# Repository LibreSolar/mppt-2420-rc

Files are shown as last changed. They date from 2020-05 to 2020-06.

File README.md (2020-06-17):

# MPPT charge controller for DIN rail mounting

 First prototype tested, but issues should still be expected.

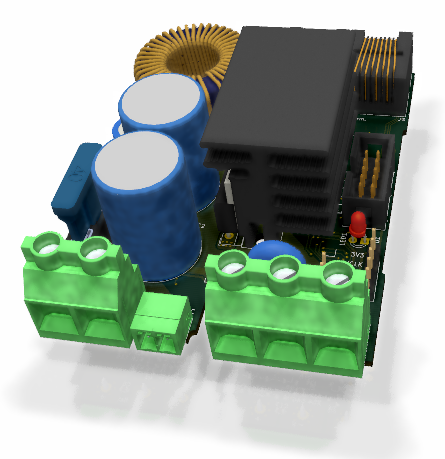
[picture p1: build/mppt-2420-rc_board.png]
MPPT 2420 RC


Schematic: [PDF file](https://github.com/LibreSolar/mppt-2420-rc/raw/master/build/mppt-2420-rc_schematic.pdf)

Bill of Materials: [CSV file](build/mppt-2420-rc_bom.csv) or [interactive HTML BOM](https://libre.solar/mppt-2420-rc/build/mppt-2420-rc_ibom.html)

## Concept description

This charge controller is mainly developed to test the following features:

- Very compact and modular housing design for DIN rail mounting
- Thermal performance and maximum heat dissipation via internal heat sinks
- Performance of the internal OpAmp of the STM32G431 MCU for current measurement
- Dump-load control for small wind turbines using the existing PV reverse blocking MOSFET

## Features

- Solar/Wind input terminal
    - Max. 80V (100V MOSFETs used)
    - DC/DC converter inductor current max. 20A
- Battery output terminal
    - 10 V - 32 V (supporting 12 V and 24 V battery systems)
    - Max. current: 20A (limited by inductor current)
- New STM32G431 ARM MCU with advanced digital power conversion features
- Expandable via Olimex Universal Extension Connector (UEXT)
- Only single LED as power indicator. Additional user interface can be included in separate PCB in front panel housing and connected via UEXT
- CAN interface via RJ45 connectors
- Optional external temperature sensor (10k NTC)
- DIN rail mounting using Phoenix Contact BC series housing

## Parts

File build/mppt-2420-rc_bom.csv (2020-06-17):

Component | References | Value | Footprint | Description | Quantity Per PCB | Manufacturer | PartNumber | Remarks
1 | C44 | 0.22µF | C_Rect_L7.2mm_W3.5mm_P5.00mm_FKS2_FKP2_MKS2_MKP2 | Unpolarized capacitor | 1 |  | 224J63
2 | C7 C9 C10 C11 C20 C22 C29 C30 C31 C32 C36 C48 | 100nF | C_0603_1608 | Unpolarized capacitor | 12 | Murata | GRM188R71H104KA93D
3 | C4 | 100nF | C_0805_2012 | Unpolarized capacitor | 1 | Murata |  | 100V, X7S
4 | C8 C14 C16 C17 C34 | 10nF | C_0603_1608 | Unpolarized capacitor | 5 | Murata | GCM188R72A103KA37D | 100V, X7R
5 | C21 C23 | 10µF | C_0805_2012 | Unpolarized capacitor | 2 | Murata | GRM21BR61E106KA73L | 25V, X5R
6 | C15 | 1nF | C_0603_1608 | Unpolarized capacitor | 1 |  |  | 50V, NP0/C0G
7 | C6 | 1nF | C_0603_1608 | Unpolarized capacitor | 1 | Murata | GRM1885C2A102JA01D | NP0/C0G
8 | C3 C18 C40 | 1µF | C_0805_2012 | Unpolarized capacitor | 3 | Murata | GRJ21BC72A105KE11L | 100V, X7S
9 | C12 C33 C39 C41 C49 | 2.2µF | C_0603_1608 | Unpolarized capacitor | 5 | Murata | GRM188R61E225KA12D | 25V, X5R
10 | C19 | 4.7µF | C_1210_3225 | Unpolarized capacitor | 1 | Murata | GRJ32DC72A475KE11L | 100V, X7S
11 | C1 C2 | 560µF | CP_Radial_D18.0mm_P7.50mm | Polarized capacitor, small symbol | 2 | United Chemi-Con | EKZN101ELL561MM25S | 100V, 2.27A, 18x25
12 | C5 | 820µF | CP_Radial_D10.0mm_P5.00mm | Polarized capacitor, small symbol | 1 | Panasonic | EEU-FR1V821L | 35V, 2.47A
13 | D5 D9 D11 | 12V | D_SOT-23_ANK | Diode zener | 3 | ON Semiconductor | SZBZX84C12LT3G | Alternative: Diodes Inc. BZX84C12-7-F
14 | D10 D16 | 1N4148 | D_SOD-123 | Diode | 2 | Diodes Inc. | 1N4148W-7-F
15 | D8 | 2.5V | D_SOD-123 | Diode zener | 1 | ON Semiconductor | MMSZ5222BT1G
16 | D2 D3 | NRVTS260ESFT1G | D_SOD-123 | Schottky diode | 2 | ON Semiconductor | NRVTS260ESFT1G | Alternative: Nexperia PMEG6020ER,115
17 | D7 D14 D15 | SS14FL | D_SOD-123 | Diode Schottky | 3 | ON Semiconductor | SS14FL | Alternative: Nexperia PMEG4010EGWX
18 | D1 | SS16FP | D_PowerDI-123 | Diode Schottky | 1 | Diodes Inc. | SS16FP | Alternative: DFLS160-7
19 | F1 | 25A | NULL | Fuse (plug-in) | 1 | Littelfuse | 0287025.PXCN
20 | F2 F3 | 600mA | Fuse_1206_3216Metric | Resettable fuse, polymeric positive temperature coefficient, small symbol | 2
21 | HS1 | Heatsink | Fischer_Elektronik_SK573_37,5 | Heatsink | 1 | Fischer Elektronik | SK573-37,5 | 3x MOSFET clips THFU 2 and thermal interface material needed
22 | J3 J4 | 8P8C | RJ45_8P8C | RJ connector, 8P8C (8 positions 8 connected), RJ31/RJ32/RJ33/RJ34/RJ35/RJ41/RJ45/RJ49/RJ61 | 2 | Amphenol FCI | 54602-908LF
23 | J6 | Conn_01x02 | PinHeader_1x02_P2.54mm_Vertical | Generic connector, single row, 01x02, script generated (kicad-library-utils/schlib/autogen/connector/) | 1
24 | J2 | MKDS 5/ 2-9,5 | Phoenix_Contact_MKDS_5-2-9,5 | Generic screw terminal 1x02 | 1 | Phoenix Contact | 1714971
25 | J1 | MKDS 5/ 3-9,5 | Phoenix_Contact_MKDS_5-3-9,5 | Generic screw terminal 1x03 | 1 | Phoenix Contact | 1714984
26 | J5 | Phoenix Contact MC 1,5 | Phoenix_Contact_MC_1,5_2-G-3,81 | Generic connector, single row, 01x02, script generated (kicad-library-utils/schlib/autogen/connector/) | 1 |  |  | Ext. Temperature Sensor
27 | J7 | UEXT | Box_Header_2x05x2.54mm_Straight | Olimex UEXT connector (2x5 box header) | 1
28 | JP1 | Jumper_NC_Small | PinHeader_1x02_P2.54mm_Vertical | Jumper, normally closed, small symbol | 1
29 | L1 | 33µH | L-FERYSTER-DTMSS-27 | Inductor with iron core | 1 | Feryster | DTMSS-27/0,033/20-H
30 | L2 | 4.7µH | L_0805_2012Metric | Inductor, small symbol | 1 | Murata | LQM21PN4R7NGRD
31 | L3 | 47µH | Bourns_SRN6045TA | Inductor, small symbol | 1 | Tayo Yuden | NR6045T470M | Alternative: Bourns SRR6045TA-470Y
32 | LED1 | red | LED_D3.0mm | Light emitting diode | 1 | Lite-On | LTST-C190KRKT | red
33 | Q9 | DMP10H4D2S | SOT-23 | P-MOSFET transistor, gate/source/drain | 1 | Diodes Inc. | DMP10H4D2S-7
34 | Q1 Q2 Q8 | IPP045N10N3G | TO-220-3_Vertical | N-MOSFET transistor, gate/drain/source | 3 | Infineon | IPP045N10N3G
35 | R12 | 0R | R_0603_1608 | Resistor | 1 | Yageo | RC0603FR-070RL
36 | R40 | 100R | R_0603_1608 | Resistor | 1 | Yageo | RC0603FR-07100RL
37 | R13 R17 | 100k | R_0603_1608 | Resistor | 2 | Yageo | RC0603FR-07100KL
38 | R7 R24 R39 R41 R45 R64 R65 R66 | 10k | R_0603_1608 | Resistor | 8 | Yageo | RC0603FR-0710KL
39 | R22 | 120R | R_1206_3216 | Resistor | 1
40 | R56 | 1M | R_0603_1608 | Resistor | 1 | Yageo | RC0603FR-071ML
41 | R15 R42 | 1k | R_0603_1608 | Resistor | 2 | Yageo | RC0603FR-071KL
42 | R8 R10 R14 R20 R21 | 2.2k | R_0603_1608 | Resistor | 5 | Yageo | RC0603FR-072K2L
43 | R4 | 2R2 | R_1206_3216 | Resistor | 1 | Yageo | RC1206FR-072R2L
44 | R6 | 2m | R_Bourns_CRE2512 | Resistor | 1 | Bourns | CRE2512-FZ-R002E-3
45 | R23 R60 | 33k | R_0603_1608 | Resistor | 2 | Yageo | RC0603FR-0733KL
46 | R1 R2 R3 R5 | 3R3 | R_0805_2012 | Resistor | 4 | Yageo | RC0805FR-073R3L
47 | R18 | 5.6k | R_0603_1608 | Resistor | 1 | Yageo | RC0603FR-075K6L
48 | R9 R11 | 68k | R_0603_1608 | Resistor | 2 | Yageo | RC0603FR-0768KL
49 | RT1 | 10k | R_0603_1608 | Temperature dependent resistor, negative temperature coefficient | 1 | TDK | NTCG163JF103FT1S
50 | RV2 | 82V | RV_Disc_D12mm_W4.3mm_P7.5mm | Voltage dependent resistor | 1 | Bourns | MOV-10D820K
51 | SWD1 | ST_Nucleo_SWD | PinHeader_1x05_P2.54mm_Vertical | STM32 Nucleo Board SWD connector (5 pins w/o SWO) | 1 | Any | Standard 2.54 mm pitch 1x5 pin header
52 | T2 T6 T10 | MMBT3904 | SOT-23 | 0.8A Ic, 45V Vce, NPN Transistor, SOT-23 | 3 | Diodes Inc. | MMBT3904-7-F
53 | U6 | 24AA32 | SOT-23-5 | Microchip 24AAxx/24LCxx I2C EEPROM, SOT-23-5 | 1 | Microchip | 24AA32AFT-I/OT
54 | U1 | LM5107 | SOIC-8_3.9x4.9mm_Pitch1.27mm | 100V / 1.4-A Peak Half Bridge Gate Driver | 1 | Texas Instruments | LM5107MAX/NOPB
55 | U4 | LMR16006X | SOT-23-6 | SIMPLE SWITCHER® 4V to 60V, 600mA Step-Down Regulator with Low Iq | 1 | Texas Instruments | LMR16006XDDCR
56 | U2 | STM32G431CBTx | LQFP-48_7x7mm_P0.5mm | ARM Cortex-M4 MCU, 128KB flash, 22KB RAM, 170MHz, 1.71-3.6V, 66 GPIO, LQFP-48 | 1 | ST Microelectronics | STM32G431CBT6
57 | U5 | TCAN334 | SOIC-8_3.9x4.9mm_Pitch1.27mm | High-Speed CAN Transceiver, 1Mbps, 3.3V supply, low power standby mode, shutdown mode, SOT-23-8/SOIC-8 | 1 | Texas Instruments | TCAN334DR
58 | U3 | TLV9001 | SOT-23-5 | SOT-23-5 | 1 | Texas Instruments | TLV9001IDBVR | Alternative: TLV6001, MCP6001
59 | XF1 | ATO blade fuse | Keystone-Fuse-3557-2 | Fuse holder | 1 | Keystone | 3557-2
60 | Y1 | 8MHz | Resonator_Murata_CSTNE | Two pin crystal | 1 | Murata | CSTNE8M00GH5C000R0 | 0.07%

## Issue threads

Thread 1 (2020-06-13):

Capacitor rev. 0.1

BernhardEllmann, 2020-06-13:
Dear Martin,

both circuit diagrams rev. 0.1 and rev. 0.1.1 specify C1 + C2 as 560 uF
BOM for rev. 0.1.1 lists 560 uF/100V
you commented that the footprint of C1 + C2 should be reduced when building the circuit on board version 0.1

do you recommend:
- to reduce 560 uF --> ?
- or to reduce 100V --> ?
- or to reduce both 560 uF / 100V --> ? / ?

my use-case is:
- solar panel 21,4 V OC, 17,5 V MP
- battery 36 V

can you please confirm that the controller can handle this? The circuit diagram does not mention that the circuit can actually be used in 2 directions

martinjaeger, 2020-06-14:
Yes, boost operation is possible, as it is a synchronous buck converter.

For the nominal 36V battery (i.e. 42V max.) also 63V or 80V caps should work fine. Slightly lower capacity (like 390uF) is also OK. Most important is that the caps allow high ripple current. If you take one from the same series as specified in the BOM everything should be fine.

BernhardEllmann, 2020-06-14:
fine, thanks a lot!

Closed 2020-06-14.

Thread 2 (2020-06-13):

faulty link?

BernhardEllmann, 2020-06-13:
right-click on
mppt-2420-rc_bom_v0.1.1.csv
at
https://github.com/LibreSolar/mppt-2420-rc/tree/master/bom

and click on
"Ziel speichern unter .. "
yields some wrong file,

whereas using "clone or Download" / "download ZIP" works well.

martinjaeger, 2020-06-14:
You should left-click on the link and then download the raw file. That's the way how github displays content of text files.

Closed 2020-06-14.

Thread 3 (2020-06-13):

BOM: some faulty part numbers

BernhardEllmann, 2020-06-13:
some part numbers in BOM, .csv-version, appear to be faulty:

- line 8 (C15): part GRM188R71H104KA93D has wrong value (0,1 uF instead of 1nF
- line 39 (R12): part RC0603FR-0710KL has wrong value (10K instead of 0R)
- line 43 (R64, R65, R66): part RC0805FR-0710KL has wrong footprint (or wrong data specified in column F)
- line 47 (R8, R10, R14): part RC0603FR-0710KL has wrong value (10k instead of 2k2)
- line 52 (R60): part RC0805FR-0733KL has wrong footprint (or wrong data specified in column F)
- line 55 (R9, R11): part RC0603FR-0710KL has wrong value (10K instead of 68K)

martinjaeger, 2020-06-14:
Thanks for finding these errors. I didn't realize them as I have all those standard parts available anyway and don't order them with each PCB.

- Line 8: Ok, taking out the specific part number, as the manufacturer doesn't matter for this part.
- Line 39: Ok, corrected.
- Line 43: Part numbers were wrong, 0603 is correct.
- Line 47: Ok, corrected.
- Line 52: 0603 footprint is correct, part number was wrong.
- Line 55: Ok, corrected.

Will push the corrections with next update.

BernhardEllmann, 2020-06-14:
Line 8: so the same type can be used as for C6, eventually? (Same footprint, same value)
If yes, the two lines 8 & 9 could be merged

btw:
C15 got changed from v0.1 to v0.1.1 (from 100 nf to 1 nF)
I guess for biuiding the circuit on board version 0.1, I shall use the updated value?

martinjaeger, 2020-06-14:
Yes, correct, 1nF can be used and the same caps can be used for both.

The snubber capacitor C6 has some influence on voltage ringing and EMC behavior and still has to be fine-tuned in the final design, so I did not merge both of them yet. But at the moment we can use the same caps for both (even though C15 doesn't need that high voltage rating).

Closed 2020-06-26.

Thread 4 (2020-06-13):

Schottky Diode SS14FL discontinued

BernhardEllmann, 2020-06-13:
Schottky Diode SS14FL dircontinued acc. to Mouser homepage (2020-06-13)

--> what should be used as a replacement?

martinjaeger, 2020-06-14:
An Alternative is already mentioned in the "Alternative" column of the BOM: Nexperia PMEG4010EGWX

Or you use the same 60V / 2A variant as suggested for the CAN bus port (see other issue).

BernhardEllmann, 2020-06-14:
oh, yes, sorry.
I had to modify my excel for several reasons, and I happened to delete this information

Closed 2020-06-14.

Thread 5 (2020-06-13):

BOM incomplete (MOSFET clips)

BernhardEllmann, 2020-06-13:
BOM appears to be incomplete:
MOSFET clips for heatsink are not included.

martinjaeger, 2020-06-14:
Thanks for these remarks. Those mechanical parts were currently not part of the BOM as KiCad does not have any feature to add parts that are not placed on the board... I will think about a way how to do that without adding them manually to the BOM after export.

The correct Heatsink clip is THFU 2. I will at least add it as a remark. Insulating pads are specified in detail yet, I just took one that I still had. For the fuse you can use Littelfuse 0287025.PXCN.

BernhardEllmann, 2020-06-14:
Why do you recommend THFU 2?
THFU 1
- is suitable for TO 220
- is suitable for SK 573
- has same strenght (60 N)
- is a tiny bit less bulky, according to technical drawing on Fischer Website (10,3 mm instead of 10,5 mm)

Have you tried THFU 1?

martinjaeger, 2020-06-14:
Good question. That one was recommended to me by Fischer Elektronik when I talked to them at Embedded World this year, so I didn't check any other option.

The THFU 2 was quite hard to mount, you needed lots of force to clip it in. Maybe THFU 1 is a bit easier to mount... but didn't try.

BernhardEllmann, 2020-06-14:
ok, I will order both and let you know :)

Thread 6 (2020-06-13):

replacement for heatsink Fischer SK 573 37,5

BernhardEllmann, 2020-06-13:
Heatsink Fischer Elektronik SK 573 37,5 seems to be hard to get.
is there any alternatives from other manufacturers?

martinjaeger, 2020-06-14:
Ok, that seems true. Only Arrow seem to have it in stock: https://octopart.com/search?q=Fischer+Elektronik+SK+573+37%2C5&currency=EUR&specs=0

I got a sample directly from Fischer Elektronik.

If you don't populate the UEXT connector J7, quite a lot of other heat sinks should be useable if the MOSFETs are screw-mounted to the heat sink. This particular one fits very well into the available space and doesn't require threads in the heat sink as it uses clips. I didn't do any research if other heat sinks fit as nicely as this one. As stated in the Readme, I still have to validate if the heat dissipation inside the housing is enough for the 20A in general.

BernhardEllmann, 2020-06-14:
the longer 50mm version is available at Farnell.
using that one after trimming would be a workaround

martinjaeger, 2020-06-14:
Ah, yes, black is recommended.

BernhardEllmann, 2020-06-14:
"If you don't populate the UEXT connector J7 ..." (cited from above)
What is the minimum setup required for programming the MC when using the v0.1 board
SWD and USART port?
(There is no debug serial port available on v0.1)

martinjaeger, 2020-06-14:
Only the SWD is needed for programming. But an USART is useful for debugging. For the v0.1 board I am using the USART in the UEXT connector, but as there was another USART left, I added a second one to the v0.1.1 board.

BernhardEllmann, 2020-06-14:
This means that you recommend to populate the UEXT port, did I understand that right?

I'm asking, because on the schematic (PDF, Page 4) the keyword "USART" shows up in combination with the keyword SWD: "STM Nucleo SWD and USART" (blue text)
(sorry. since I'm not too familiar with these ports yet, it's a little bit confusing for me)

martinjaeger, 2020-06-14:
The UEXT port is very useful, as you can add lots of extensions to the board, see here: https://www.olimex.com/Products/Modules/

However, if you need the space for a different heat sink and still want to use the USART for debugging (which I highly recommend), you can also solder those two wires to the correct pins at the UEXT connector only.

The text refers to SWD and USART at the same time as both are quite useful during development and most programmers / debug probes (including the ST-Link v2 as included in many ST nucleo boards) also have the USART pins that you can use for printing serial debug information.

BernhardEllmann, 2020-06-14:
sounds good, thank you!

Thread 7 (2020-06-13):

BOM consolidation: C8, C14, C16, C34 vs. C17

BernhardEllmann, 2020-06-13:
Why use different types for:
- C8, C14, C16: 50V
- C17: 100V

could 100V type be used for all 4 components?

martinjaeger, 2020-06-14:
Thanks for these enhancements.

- C17 etc. (10 nF): I agree this makes sense. Will update this.
- C41 etc. (2.2uF): I forgot to add the part number in the schematic for one of them, so the BOM export puts it in a separate line as their information was not *exactly* the same. Just added the number also for C41, so it will get to the same line for next export.
- D2, D3: Oops, forgot to specify as I just took one of the SS14FL. We could actually consolidate the different types of Schottky diodes better and just use 60V / 2A versions everywhere. Suitable parts:
Nexperia PMEG6020ER,115 or ON Semi NRVTS260ESFT1G
- J3, J4: Amphenol FCI 54602-908LF (will add it to the BOM aswell)

BernhardEllmann, 2020-06-14:
thanks to your here too !

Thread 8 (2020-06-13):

replacement for F2, F3?

BernhardEllmann, 2020-06-13:
In case Fuse 600mA 1206 is not available:
- use slightly lower value instead (e.g. 460mA)?
- use slightly higher value instead (e.g. 750mA)?
please give a range.

martinjaeger, 2020-06-14:
I assume you don't need the CAN bus part for your application anyway, so you can leave out that sheet of the circuit completely.

The fuse protects the RJ45 wires from overcurrent and they can handle around 300 mA per wire pair (we use two pairs). Allowing less current is always safe.

BernhardEllmann, 2020-06-14:
ok, good to know, thank you!

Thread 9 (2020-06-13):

J5 external temperature sensor

BernhardEllmann, 2020-06-13:
what happens if J5 remains open?

If I want to use J5:
- what sensor do i need to use?
- what connector matches with J5?
Please specify

martinjaeger, 2020-06-14:
The firmware assumes 25°C if no external sensor is connected. And as Li-Ion charging voltages are not temperature-dependent, it's only relevant for lead-acid batteries.

You can use any wired 10k NTC with a connector from Phoenix Contact FMC 1,5 3,81 series (or similar one from other brands). A suitable Phoenix Contact part number is 1745894.

Thanks for the remark, I will add this to the schematic.

BernhardEllmann, 2020-06-14:
ok, fine, thanks a lot!

Closed 2020-06-14.

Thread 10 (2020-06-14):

HV / LV side to 3.3V

BernhardEllmann, 2020-06-14:
The diagram on Page 3 page of PDF "mppt-2420-rc" (sheet "/Power Supply/") defines "HV +" as power input, which is linked to DCDC_HV+ on Page 1 (sheet "/").
Accordingly, the circuit board (version v0.1) is hardwired to DCDC_HV+

At the same time, Page 3 states: "Use voltage from low side if available."
This seems to offer a choice which is actually not available.

Please explain.

martinjaeger, 2020-06-14:
The Power Supply sheet uses the name HV+ internally, but it's connected to the DCDC_HV+ net on the top level schematic.

The circuit around Q9 in the Power Supply sheet "chooses" automatically, which rail (HV+ or LV+) it uses for internal power supply. If LV+ is available (>around 12V), it is used instead of HV+ to increase efficiency.

BernhardEllmann, 2020-06-14:
well, that's a nice feature :)

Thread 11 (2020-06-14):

boost mode operation?

BernhardEllmann, 2020-06-14:
I'm still wondering, if / why the controller can operate in boost mode (solar panel @18 V; Battery @ 36)

If I understood you correctly on the phone, this would involve connecting the battery to the HV side, and the solar panel to the LV side. But then the current would have opposite direction, right?
- Can the MOSFETS cope with that?
- What about "MOSFET for reverse polarity protection and PV reverse current blocking" (Schematic, Page 2, sheet "DC/DC", blue text next to Q8)

Is there any tutorial available?

martinjaeger, 2020-06-14:
Yep, see here: https://learn.libre.solar/development/dcdc_converter.html

The reverse polarity protection MOSFET will be switched on as soon as the DC/DC power stage is switched on. And if you use a connector where you can't connect the converter in reverse polarity, you can even use the terminal that goes directly to GNDPWR (marked W- for wind negative terminal).

BernhardEllmann, 2020-06-14:
nice.
But it does mean that the MOSFETs have to be able to cope with bidirectional current, right?
What about the in-built diodes in the MOSFETs, as indicated in the wiring symbols?

martinjaeger, 2020-06-14:
A MOSFET that is switched on does not care about the direction of current flow. And when it's off, current can only go in one direction (through the [body diode](https://en.wikipedia.org/wiki/Power_MOSFET#Body_diode)). And that's the same direction as you would have in a non-synchronous buck or boost converter.

BernhardEllmann, 2020-06-14:
ok, I think I got it now, thank you!

Closed 2020-06-25.

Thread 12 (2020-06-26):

Interference of external and internal OpAmp

martinjaeger, 2020-06-26:
The board has an external OpAmp as stuffing option. However, during testing with the external OpAmp, we realized that the microcontroller pins influence the OpAmp operation even if they are in high impedance state.

Solution: Cut the the three traces to the internal OpAmp (see following picture) with a knife if the external one should be used.

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

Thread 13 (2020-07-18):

SMPS power supply HV+/LV+ switching not working properly

martinjaeger, 2020-07-18:
For 24V systems, the maximum voltage ratings of T2 base are exceeded, which leads to excessive current draw.

Preliminary solutions:
- Replace T2 with NMOS (e.g. BSS138)
- Remove T2 completely (and use only low voltage side for power supply)

Permanent fix yet to be developed.

For details see [Forum post](https://talk.libre.solar/t/building-mppt-2420-rc-solar-charger/194/2).

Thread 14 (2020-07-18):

Q8 gate drive via half bridge driver via not sufficient

martinjaeger, 2020-07-18:
Already in previous MPPT designs, the reverse blocking MOSFET (here: Q8) was supplied via the low-side gate driver of the half bridge, switching it on automatically when the power stage is on.

In this design the reverse blocking MOSFET can be used also as a dump load switch for wind turbine applications (with the generator negative connected via separate terminal W-), so it should be possible to switch it on even if the power stage is off. R12 allows to supply power directly from the 12V rail.

Unfortunately, the 10k pull-up resistor R45 necessary for this use case prevents the MOSFET Q8 to stay on if powered by the low-side driver, especially at low duty cycles.

Preliminary solution:
- Populate 0R resistor R12 (leading to slightly higher power consumption when power stage is off)
- Replace R45 with a 0R resistor (solder bridge) and remove R12 and T6

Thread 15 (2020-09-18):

mppt-2420 - support for higher voltage and current

lwqcz, 2020-09-18:
Hi there,

what I need to change to support 300V input from my photovoltaic panels and 40A current to battery?

Just different inductor and MOSFETs?

Thank you.

martinjaeger, 2020-09-18:
That would be a completely different design, probably with a two-phase power stage.

lwqcz, 2020-09-29:
I see... And what about an idea of an addon module for higher voltage and load, isolated via optocoupler?

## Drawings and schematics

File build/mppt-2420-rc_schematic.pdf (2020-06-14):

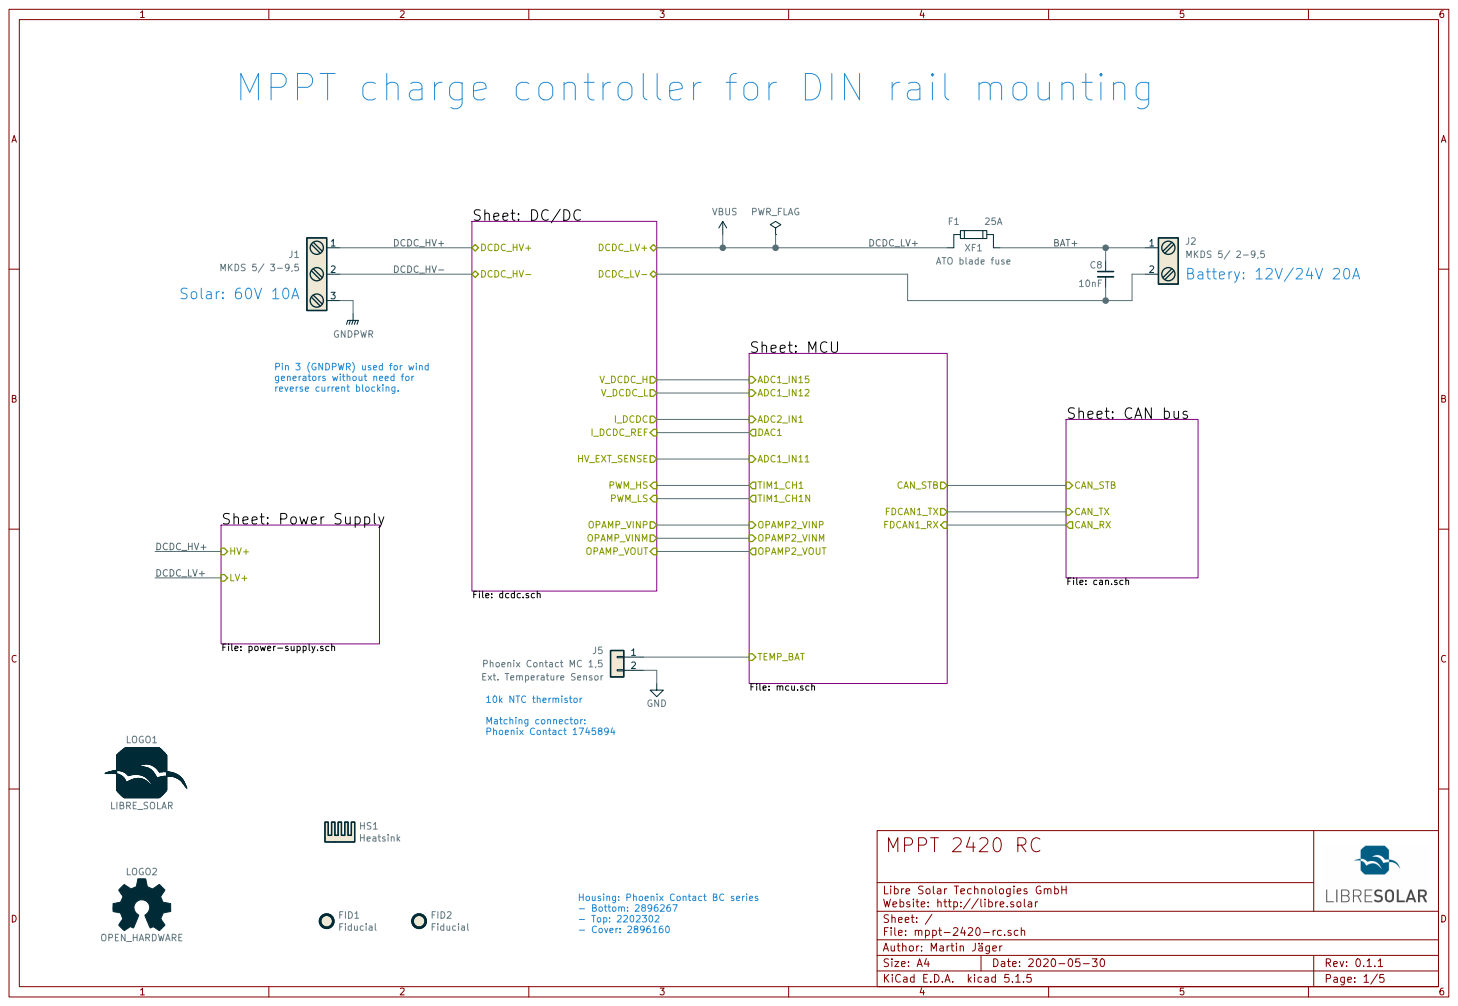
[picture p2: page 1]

10k NTC thermistor Matching connector: Phoenix Contact 1745894 MPPT charge controller for DIN rail mounting

File: can.sch CAN_TX CAN_RX CAN_STB Sheet: DC/DC

XF1 ATO blade fuse GNDPWR

Pin 3 (GNDPWR) used for wind
generators without need for
reverse current blocking.

File: power-supply.sch

J5 Phoenix Contact MC 1,5 Ext. Temperature Sensor

File: mppt-2420-rc.sch Sheet: / Libre Solar Technologies GmbH
Website: http://libre.solar

Housing: Phoenix Contact BC series
- Bottom: 2896267
- Top: 2202302
- Cover: 2896160

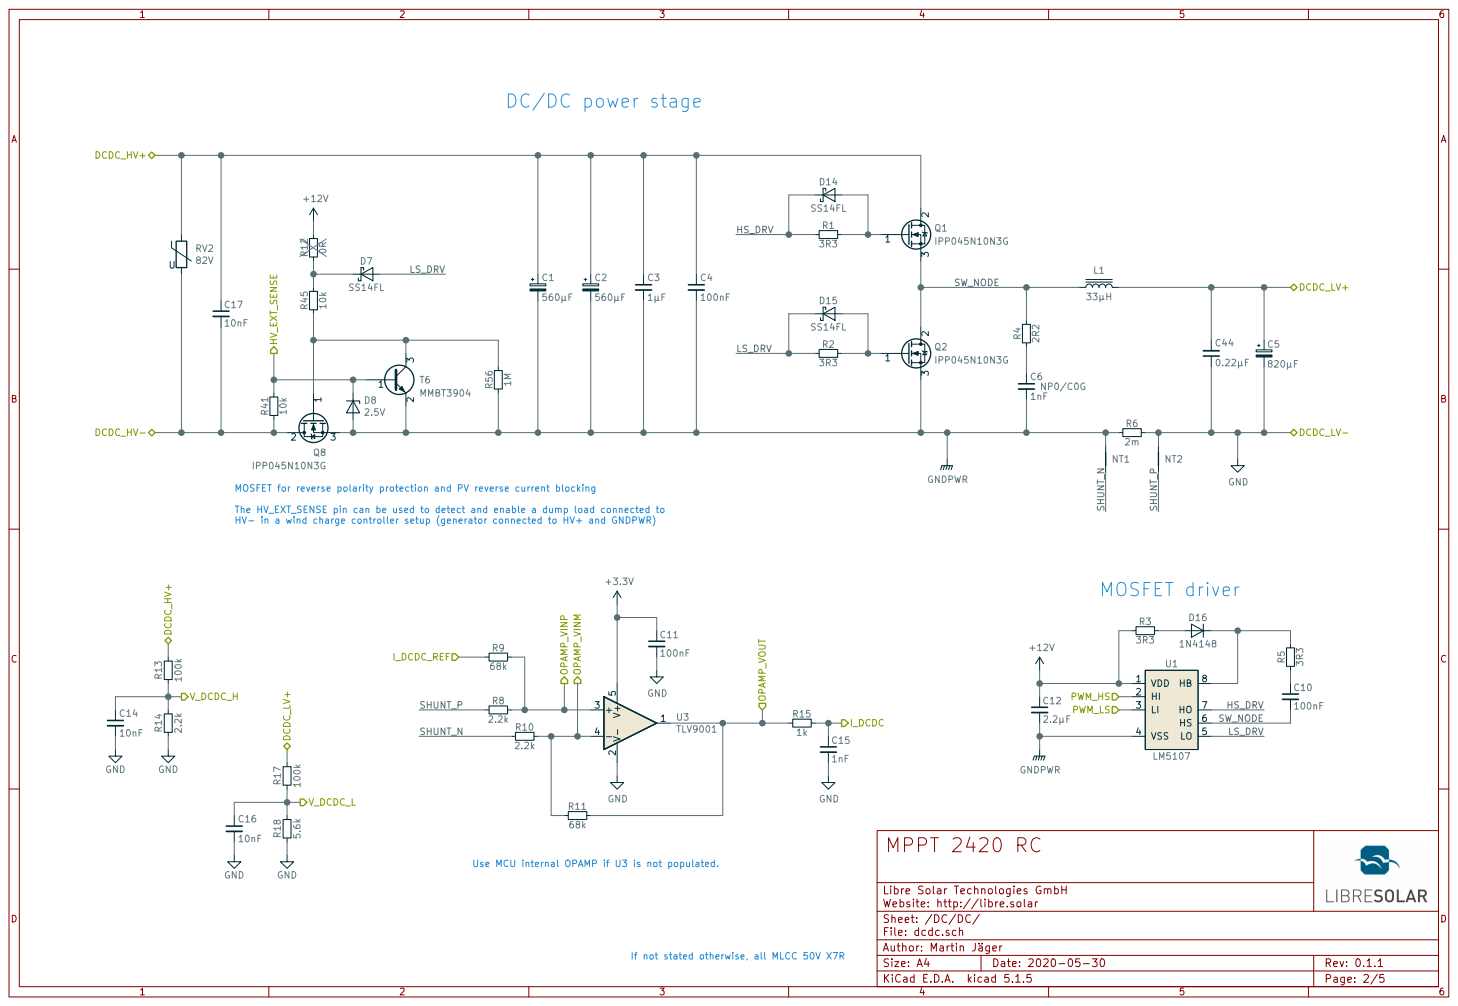
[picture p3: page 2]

DC/DC power stage

HS_DRV MOSFET for reverse polarity protection and PV reverse current blocking

The HV_EXT_SENSE pin can be used to detect and enable a dump load connected to
HV- in a wind charge controller setup (generator connected to HV+ and GNDPWR)

Use MCU internal OPAMP if U3 is not populated.

File: dcdc.sch Sheet: /DC/DC/ Libre Solar Technologies GmbH

If not stated otherwise, all MLCC 50V X7R

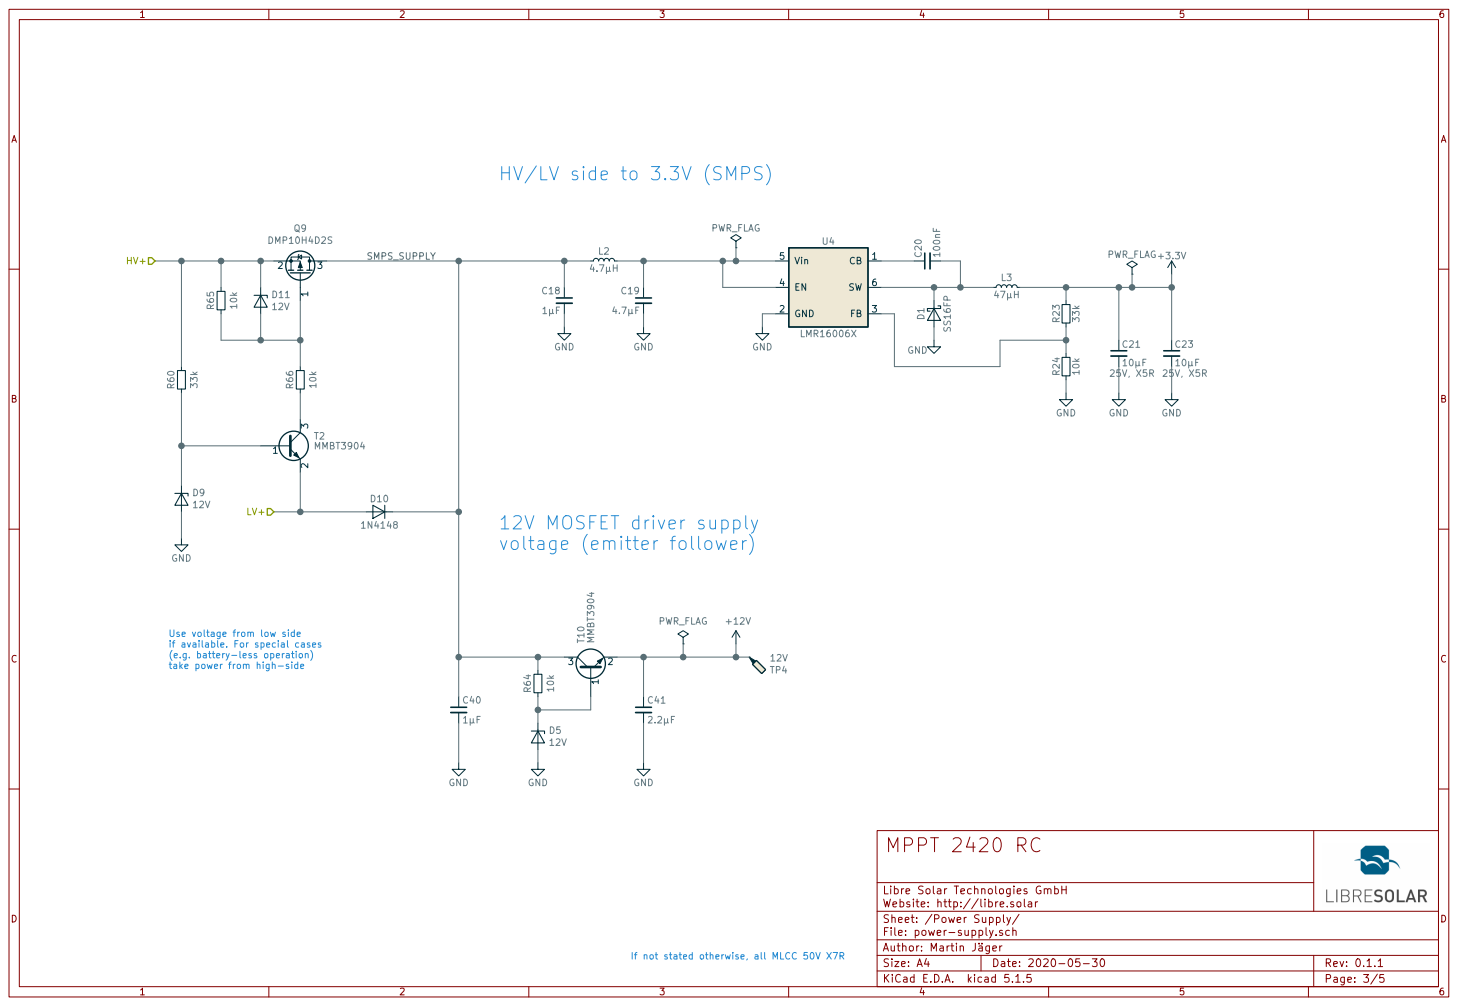
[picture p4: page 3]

HV/LV side to 3.3V (SMPS)

Use voltage from low side
if available. For special cases
(e.g. battery-less operation)
take power from high-side

Website: http://libre.solar GND

Libre Solar Technologies GmbH

Sheet: /Power Supply/
File: power-supply.sch
Author: Martin Jäger

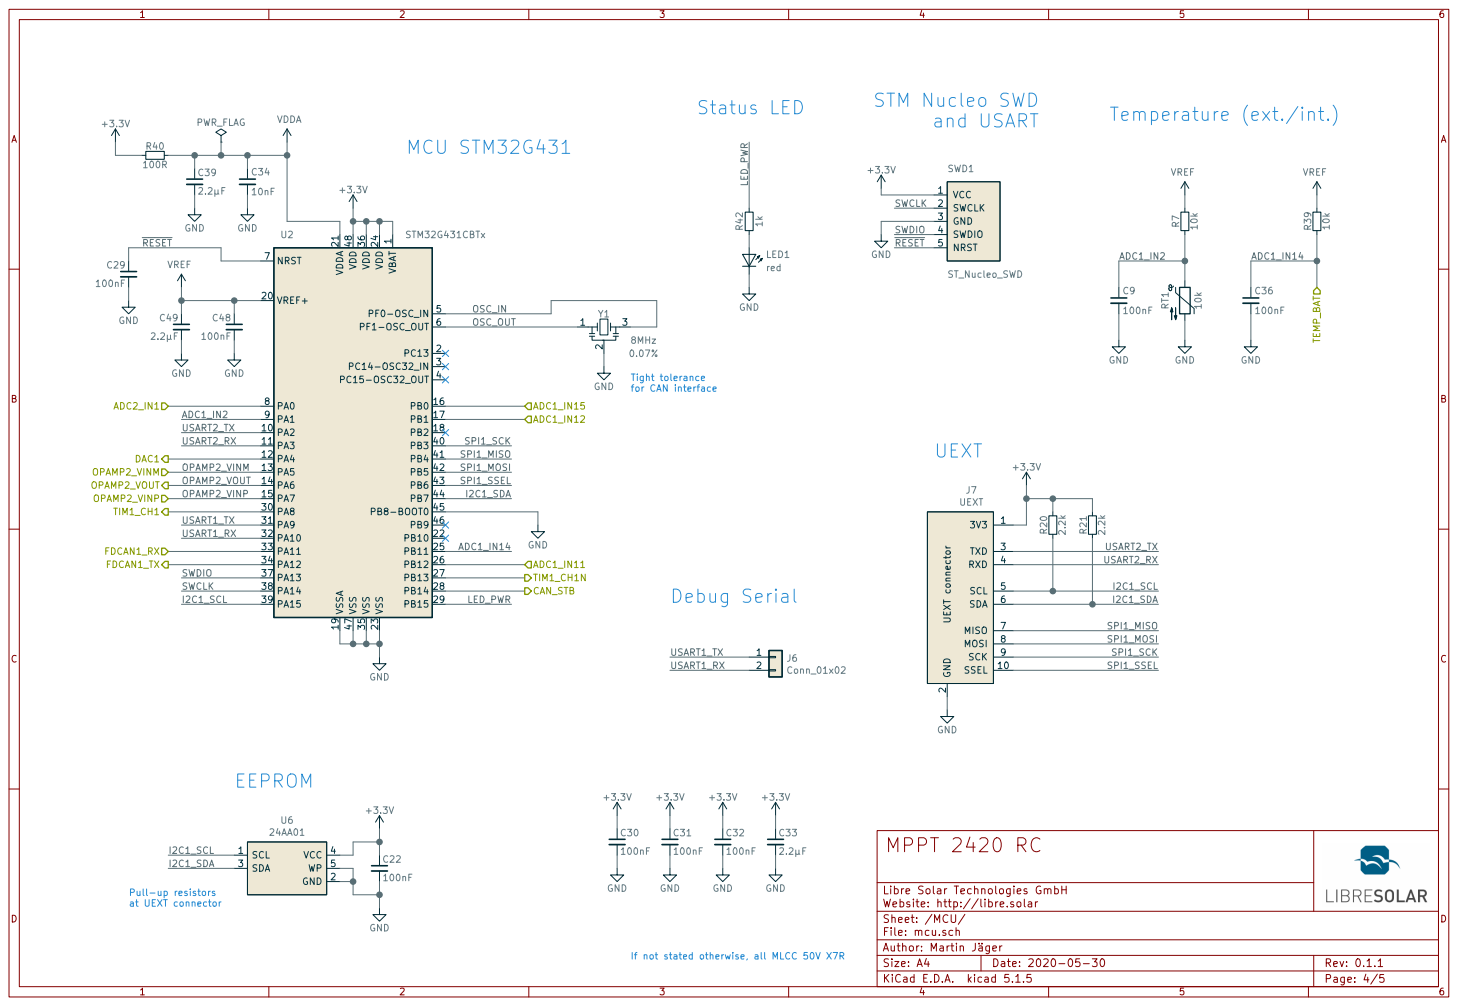
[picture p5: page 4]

1 PA2 10 PA3 11 PA4 12 PA5 13 PA6 14 PA7 15 PB0 16 PB1 17 PB2 18 VSSA 19 PC13 2 VREF+ 20 VDDA 21 PB10 22 VSS 23 VDD 24 PB11 25 PB12 26 PB13 27 PB14 28 PB15 29 PC14-OSC32_IN 3 PA8 30 PA9 31 PA10 32 PA11 33 PA12 34 VSS 35 VDD 36 PA13 37 PA14 38 PA15 39 PC15-OSC32_OUT 4 PB3 40 PB4 41 PB5 42 PB6 43 PB7 44 PB8-BOOT0 45 PB9 46 VSS 47 VDD 48 PF0-OSC_IN 5 PF1-OSC_OUT 6 NRST 7 PA0 8 PA1 9 U2 STM32G431CBTx VREF C49

Tight tolerance
for CAN interface Debug Serial

2 TXD 3 SCL 5 SDA 6 MISO 7 MOSI 8 SCK 9

File: mcu.sch Sheet: /MCU/ Libre Solar Technologies GmbH
Website: http://libre.solar

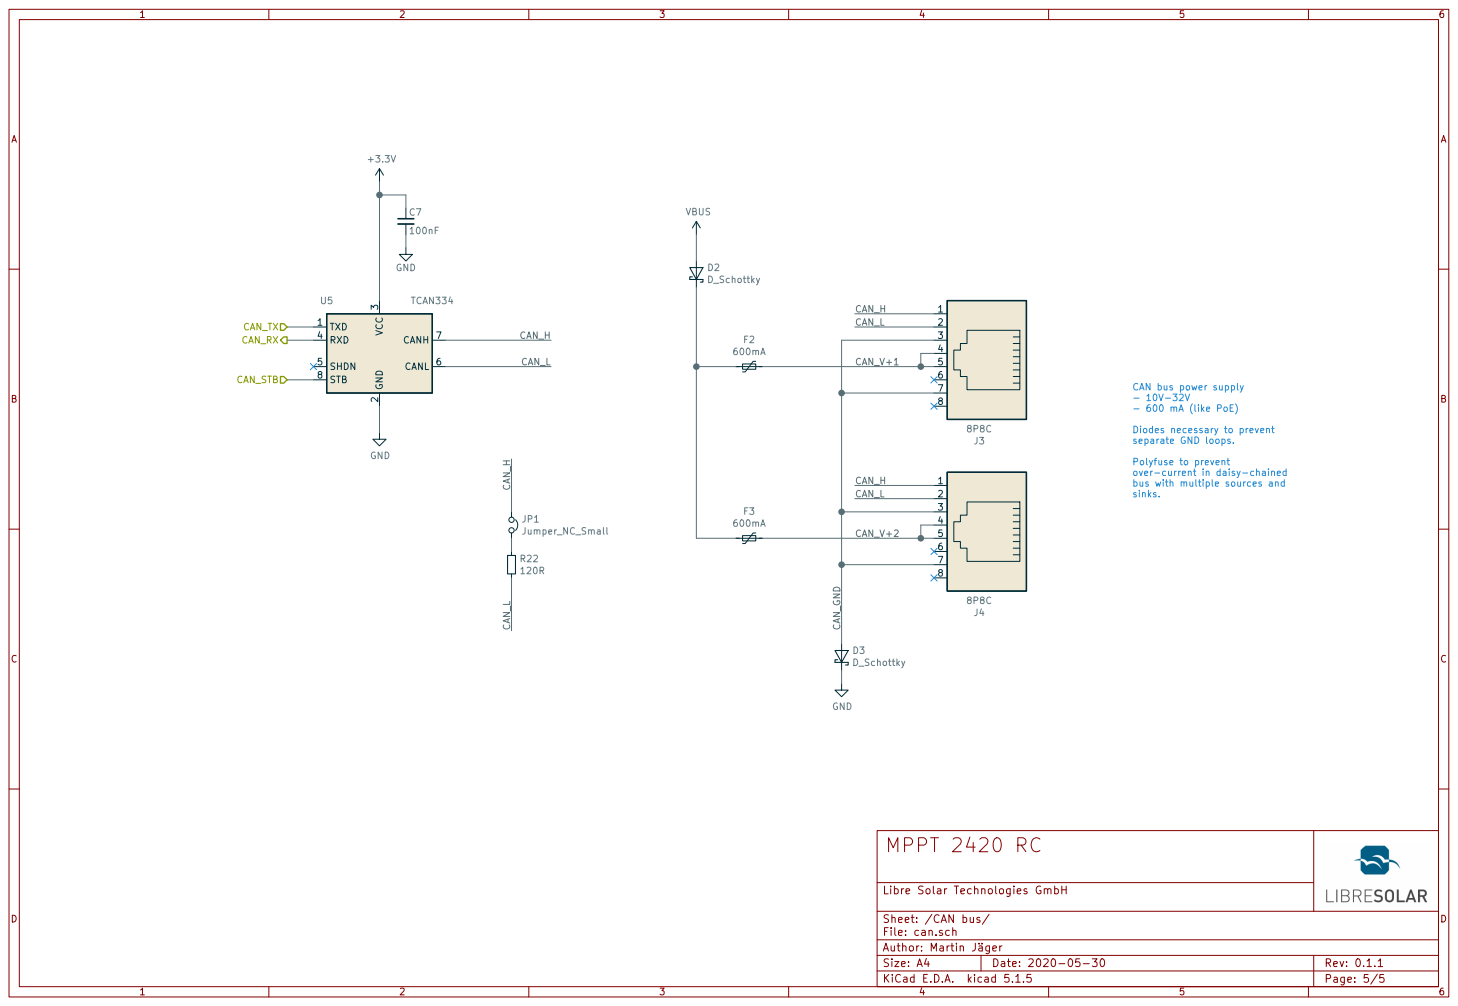
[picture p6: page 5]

3 RXD 4 SHDN 5 CANL 6 CANH 7 STB 8U5 TCAN334

CAN bus power supply
- 600 mA (like PoE)

Diodes necessary to prevent
separate GND loops.

Polyfuse to prevent
over-current in daisy-chained
bus with multiple sources and sinks.

File: can.sch Sheet: /CAN bus/ Libre Solar Technologies GmbH

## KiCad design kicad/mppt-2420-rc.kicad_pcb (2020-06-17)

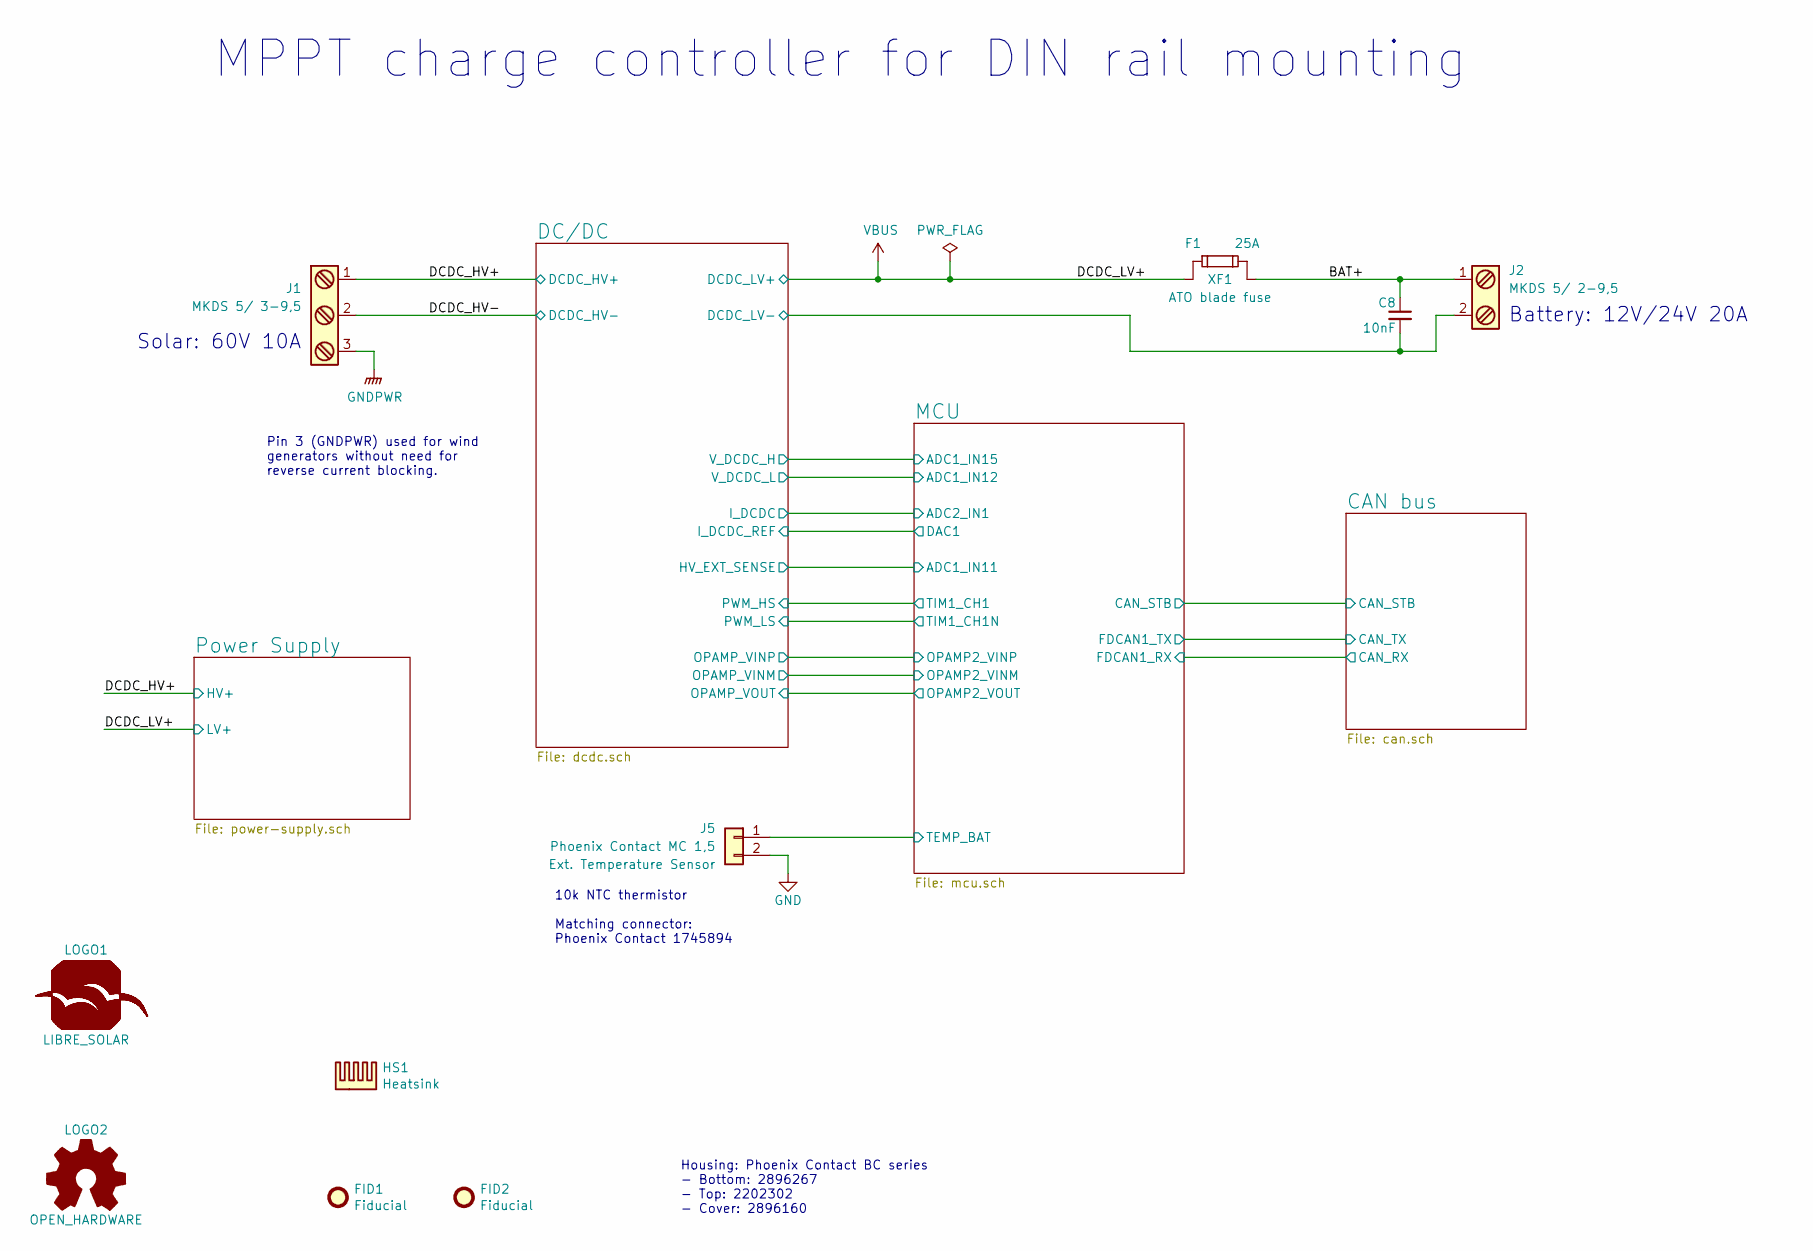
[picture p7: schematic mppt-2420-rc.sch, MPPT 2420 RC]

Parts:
C8: 10nF; C_0603_1608; PartNumber GCM188R72A103KA37D
F1: 25A; NULL; PartNumber 0287025.PXCN
FID1, FID2: Fiducial; Fiducial_0.7mm
HS1: Heatsink; Fischer_Elektronik_SK573_37,5; PartNumber SK573-37,5
J1: MKDS 5/ 3-9,5; Phoenix_Contact_MKDS_5-3-9,5; PartNumber 1714984
J2: MKDS 5/ 2-9,5; Phoenix_Contact_MKDS_5-2-9,5; PartNumber 1714971
J5: Phoenix Contact MC 1,5; Phoenix_Contact_MC_1,5_2-G-3,81
LOGO1: LIBRE_SOLAR; LIBRESOLAR_LOGO
LOGO2: OPEN_HARDWARE; OSHW-Logo_5.7x6mm_SilkScreen
XF1: ATO blade fuse; Keystone-Fuse-3557-2; PartNumber 3557-2

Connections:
/BAT+: C8.1, J2.1, XF1.2
/DCDC_HV+: J1.1; also elsewhere on the board
/DCDC_HV-: J1.2; also elsewhere on the board
/MCU/TEMP_BAT: J5.1; also elsewhere on the board
GND: C8.2, J2.2, J5.2; also elsewhere on the board
GNDPWR: J1.3; also elsewhere on the board
VBUS: XF1.1; also elsewhere on the board

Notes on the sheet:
MPPT charge controller for DIN rail mounting
Solar: 60V 10A
Battery: 12V/24V 20A
Pin 3 (GNDPWR) used for wind generators without need for reverse current blocking.
Housing: Phoenix Contact BC series - Bottom: 2896267 - Top: 2202302 - Cover: 2896160
10k NTC thermistor Matching connector: Phoenix Contact 1745894

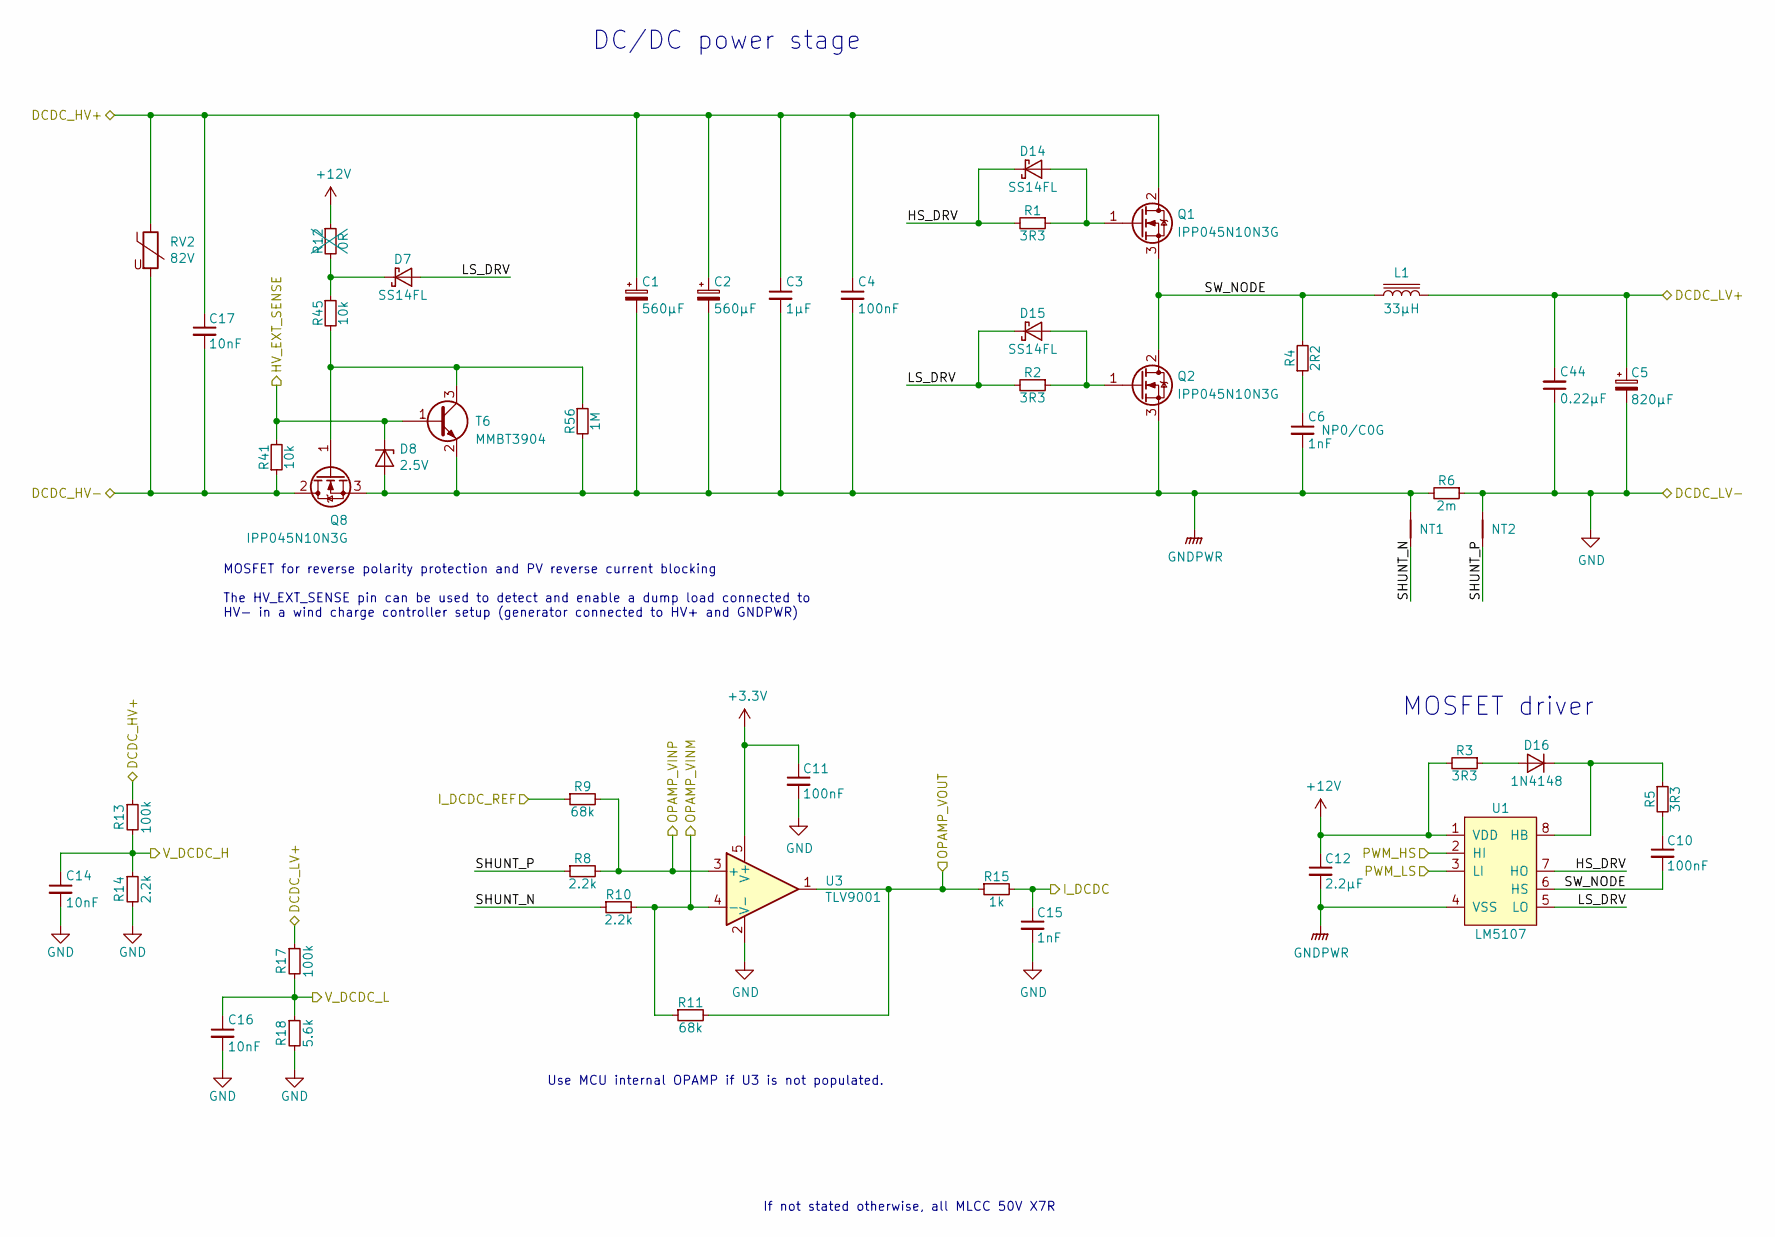
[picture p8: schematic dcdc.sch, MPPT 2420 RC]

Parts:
C1, C2: 560µF; CP_Radial_D18.0mm_P7.50mm; PartNumber EKZN101ELL561MM25S
C3: 1µF; C_0805_2012; PartNumber GRJ21BC72A105KE11L
C4: 100nF; C_0805_2012
C5: 820µF; CP_Radial_D10.0mm_P5.00mm; PartNumber EEU-FR1V821L
C6: 1nF; C_0603_1608; PartNumber GRM1885C2A102JA01D
C10, C11: 100nF; C_0603_1608; PartNumber GRM188R71H104KA93D
C12: 2.2µF; C_0603_1608; PartNumber GRM188R61E225KA12D
C14, C16, C17: 10nF; C_0603_1608; PartNumber GCM188R72A103KA37D
C15: 1nF; C_0603_1608
C44: 0.22µF; C_Rect_L7.2mm_W3.5mm_P5.00mm_FKS2_FKP2_MKS2_MKP2; PartNumber 224J63
D7, D14, D15: SS14FL; D_SOD-123; PartNumber SS14FL
D8: 2.5V; D_SOD-123; PartNumber MMSZ5222BT1G
D16: 1N4148; D_SOD-123; PartNumber 1N4148W-7-F
L1: 33µH; L-FERYSTER-DTMSS-27; PartNumber DTMSS-27/0,033/20-H
NT1, NT2: Net-Tie_2; NetTie-2_SMD_Pad0.5mm
Q1, Q2, Q8: IPP045N10N3G; TO-220-3_Vertical; PartNumber IPP045N10N3G
R1, R2, R3, R5: 3R3; R_0805_2012; PartNumber RC0805FR-073R3L
R4: 2R2; R_1206_3216; PartNumber RC1206FR-072R2L
R6: 2m; R_Bourns_CRE2512; PartNumber CRE2512-FZ-R002E-3
R8, R10, R14: 2.2k; R_0603_1608; PartNumber RC0603FR-072K2L
R9, R11: 68k; R_0603_1608; PartNumber RC0603FR-0768KL
R12: 0R; R_0603_1608; PartNumber RC0603FR-070RL
R13, R17: 100k; R_0603_1608; PartNumber RC0603FR-07100KL
R15: 1k; R_0603_1608; PartNumber RC0603FR-071KL
R18: 5.6k; R_0603_1608; PartNumber RC0603FR-075K6L
R41, R45: 10k; R_0603_1608; PartNumber RC0603FR-0710KL
R56: 1M; R_0603_1608; PartNumber RC0603FR-071ML
RV2: 82V; RV_Disc_D12mm_W4.3mm_P7.5mm; PartNumber MOV-10D820K
T6: MMBT3904; SOT-23; PartNumber MMBT3904-7-F
U1: LM5107; SOIC-8_3.9x4.9mm_Pitch1.27mm; PartNumber LM5107MAX/NOPB
U3: TLV9001; SOT-23-5; PartNumber TLV9001IDBVR

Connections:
+3V3: C11.1, U3.5 (V+); also elsewhere on the board
+12V: C12.1, R3.2, R12.1, U1.1 (VDD); also elsewhere on the board
/DC/DC/HS_DRV: D14.1 (K), R1.2, U1.7 (HO)
/DC/DC/LS_DRV: D7.2 (A), D15.1 (K), R2.2, U1.5 (LO)
/DC/DC/PWM_HS: U1.2 (HI); also elsewhere on the board
/DC/DC/PWM_LS: U1.3 (LI); also elsewhere on the board
/DC/DC/SHUNT_N: NT1.2, R10.1
/DC/DC/SHUNT_P: NT2.2, R8.1
/DC/DC/SW_NODE: C10.2, L1.1, Q1.3 (S), Q2.2 (D), R4.2, U1.6 (HS)
/DCDC_HV+: C1.1, C2.1, C3.1, C4.1, C17.1, Q1.2 (D), R13.1, RV2.1; also elsewhere on the board
/DCDC_HV-: C17.2, Q8.2 (D), R41.1, RV2.2; also elsewhere on the board
/MCU/ADC1_IN11: D8.1 (K), R41.2, T6.1 (B); also elsewhere on the board
/MCU/ADC1_IN12: C16.1, R17.2, R18.1; also elsewhere on the board
/MCU/ADC1_IN15: C14.1, R13.2, R14.1; also elsewhere on the board
/MCU/ADC2_IN1: C15.1, R15.2; also elsewhere on the board
/MCU/DAC1: R9.1; also elsewhere on the board
/MCU/OPAMP2_VINM: R10.2, R11.1, U3.4 (-); also elsewhere on the board
/MCU/OPAMP2_VINP: R8.2, R9.2, U3.3 (+); also elsewhere on the board
/MCU/OPAMP2_VOUT: R11.2, R15.1, U3.1; also elsewhere on the board
GND: C5.2, C11.2, C14.2, C15.2, C16.2, C44.1, NT2.1, R6.1, R14.2, R18.2, U3.2 (V-); also elsewhere on the board
GNDPWR: C1.2, C2.2, C3.2, C4.2, C6.2, C12.2, D8.2 (A), NT1.1, Q2.3 (S), Q8.3 (S), R6.2, R56.2, T6.2 (E), U1.4 (VSS); also elsewhere on the board
unnamed: C6.1, R4.1
unnamed: C10.1, R5.2
unnamed: D7.1 (K), R12.2, R45.1
unnamed: D14.2 (A), Q1.1 (G), R1.1
unnamed: D15.2 (A), Q2.1 (G), R2.1
unnamed: D16.1 (K), R5.1, U1.8 (HB)
unnamed: D16.2 (A), R3.1
unnamed: Q8.1 (G), R45.2, R56.1, T6.3 (C)
VBUS: C5.1, C44.2, L1.2, R17.1; also elsewhere on the board

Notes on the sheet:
DC/DC power stage
MOSFET driver
If not stated otherwise, all MLCC 50V X7R
MOSFET for reverse polarity protection and PV reverse current blocking The HV_EXT_SENSE pin can be used to detect and enable a dump load connected to HV- in a wind charge controller setup (generator connected to HV+ and GNDPWR)
Use MCU internal OPAMP if U3 is not populated.

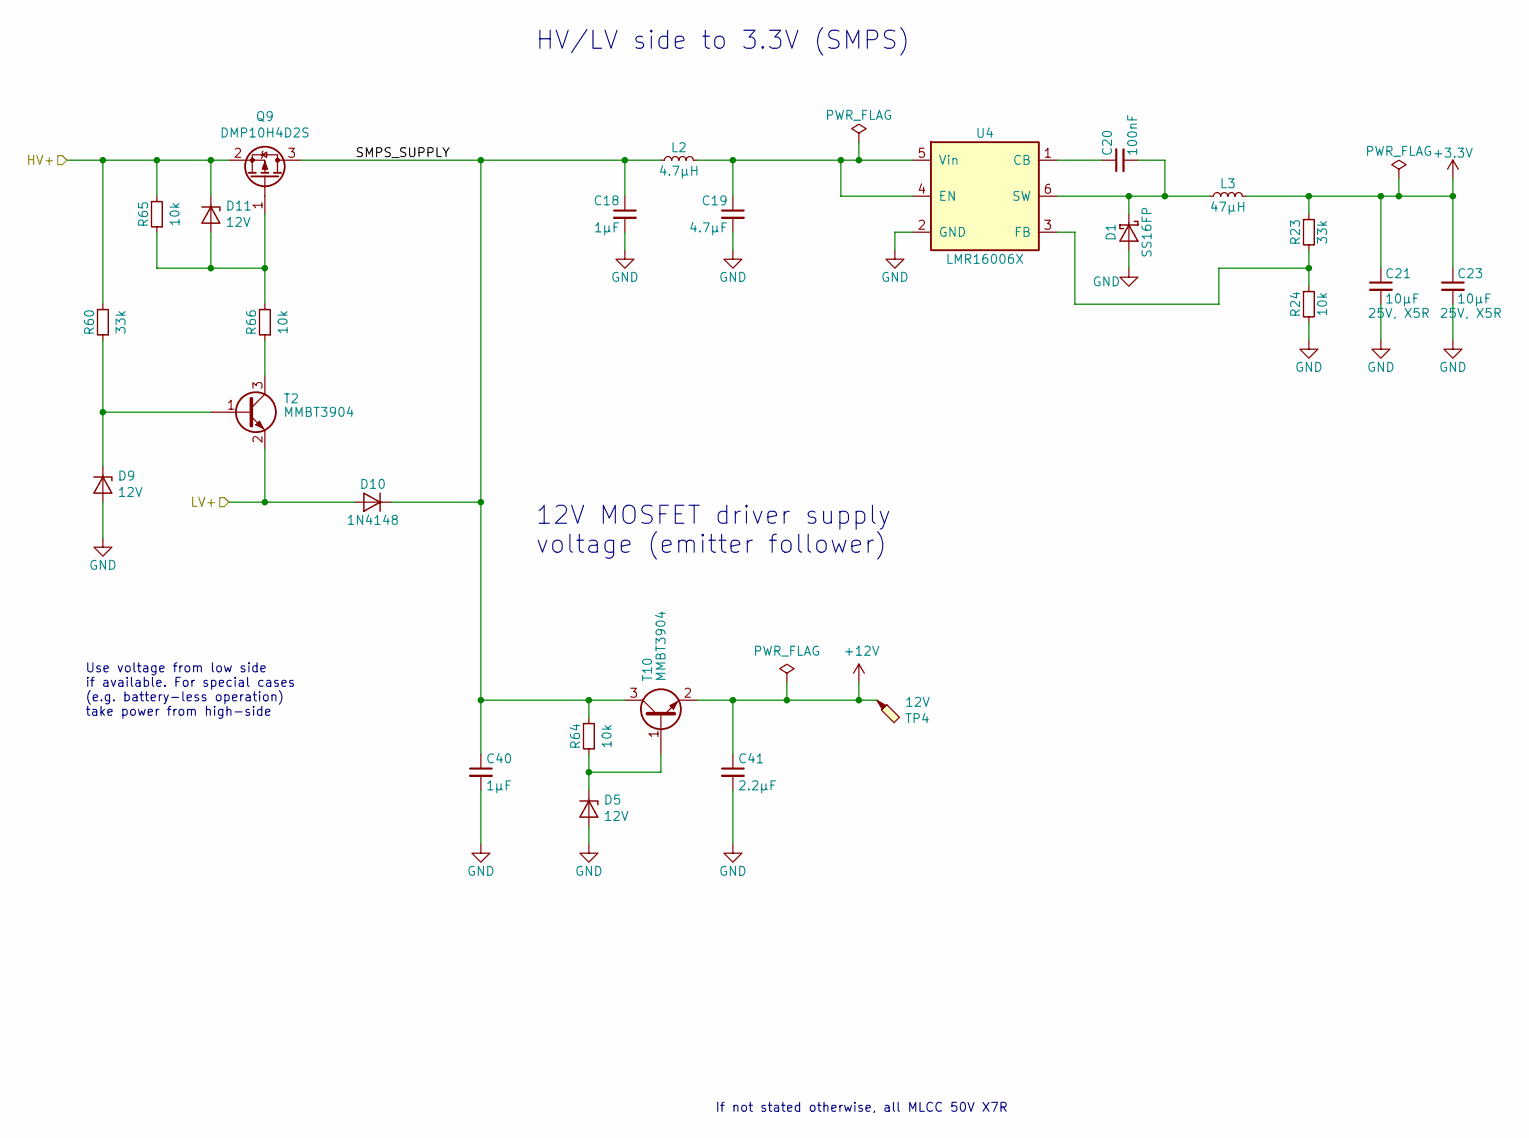
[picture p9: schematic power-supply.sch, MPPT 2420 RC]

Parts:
C18, C40: 1µF; C_0805_2012; PartNumber GRJ21BC72A105KE11L
C19: 4.7µF; C_1210_3225; PartNumber GRJ32DC72A475KE11L
C20: 100nF; C_0603_1608; PartNumber GRM188R71H104KA93D
C21, C23: 10µF; C_0805_2012; PartNumber GRM21BR61E106KA73L
C41: 2.2µF; C_0603_1608; PartNumber GRM188R61E225KA12D
D1: SS16FP; D_PowerDI-123; PartNumber SS16FP
D5, D9, D11: 12V; D_SOT-23_ANK; PartNumber SZBZX84C12LT3G
D10: 1N4148; D_SOD-123; PartNumber 1N4148W-7-F
L2: 4.7µH; L_0805_2012Metric; PartNumber LQM21PN4R7NGRD
L3: 47µH; Bourns_SRN6045TA; PartNumber NR6045T470M
Q9: DMP10H4D2S; SOT-23; PartNumber DMP10H4D2S-7
R23, R60: 33k; R_0603_1608; PartNumber RC0603FR-0733KL
R24, R64, R65, R66: 10k; R_0603_1608; PartNumber RC0603FR-0710KL
T2, T10: MMBT3904; SOT-23; PartNumber MMBT3904-7-F
TP4: 12V; TestPoint_Pad_D1.0mm
U4: LMR16006X; SOT-23-6; PartNumber LMR16006XDDCR

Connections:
+3V3: C21.1, C23.1, L3.2, R23.1; also elsewhere on the board
+12V: C41.1, T10.2 (E), TP4.1; also elsewhere on the board
/DCDC_HV+: D11.1 (K), Q9.2 (S), R60.2, R65.2; also elsewhere on the board
/Power Supply/SMPS_SUPPLY: C18.1, C40.1, D10.1 (K), L2.1, Q9.3 (D), R64.2, T10.3 (C)
GND: C18.2, C19.2, C21.2, C23.2, C40.2, C41.2, D1.2 (A), D5.2 (A), D9.2 (A), R24.2, U4.2 (GND); also elsewhere on the board
unnamed: C19.1, L2.2, U4.4 (EN), U4.5 (Vin)
unnamed: C20.1, U4.1 (CB)
unnamed: C20.2, D1.1 (K), L3.1, U4.6 (SW)
unnamed: D5.1 (K), R64.1, T10.1 (B)
unnamed: D9.1 (K), R60.1, T2.1 (B)
unnamed: D11.2 (A), Q9.1 (G), R65.1, R66.2
unnamed: R23.2, R24.1, U4.3 (FB)
unnamed: R66.1, T2.3 (C)
VBUS: D10.2 (A), T2.2 (E); also elsewhere on the board

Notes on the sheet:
HV/LV side to 3.3V (SMPS)
If not stated otherwise, all MLCC 50V X7R
12V MOSFET driver supply voltage (emitter follower)
Use voltage from low side if available. For special cases (e.g. battery-less operation) take power from high-side

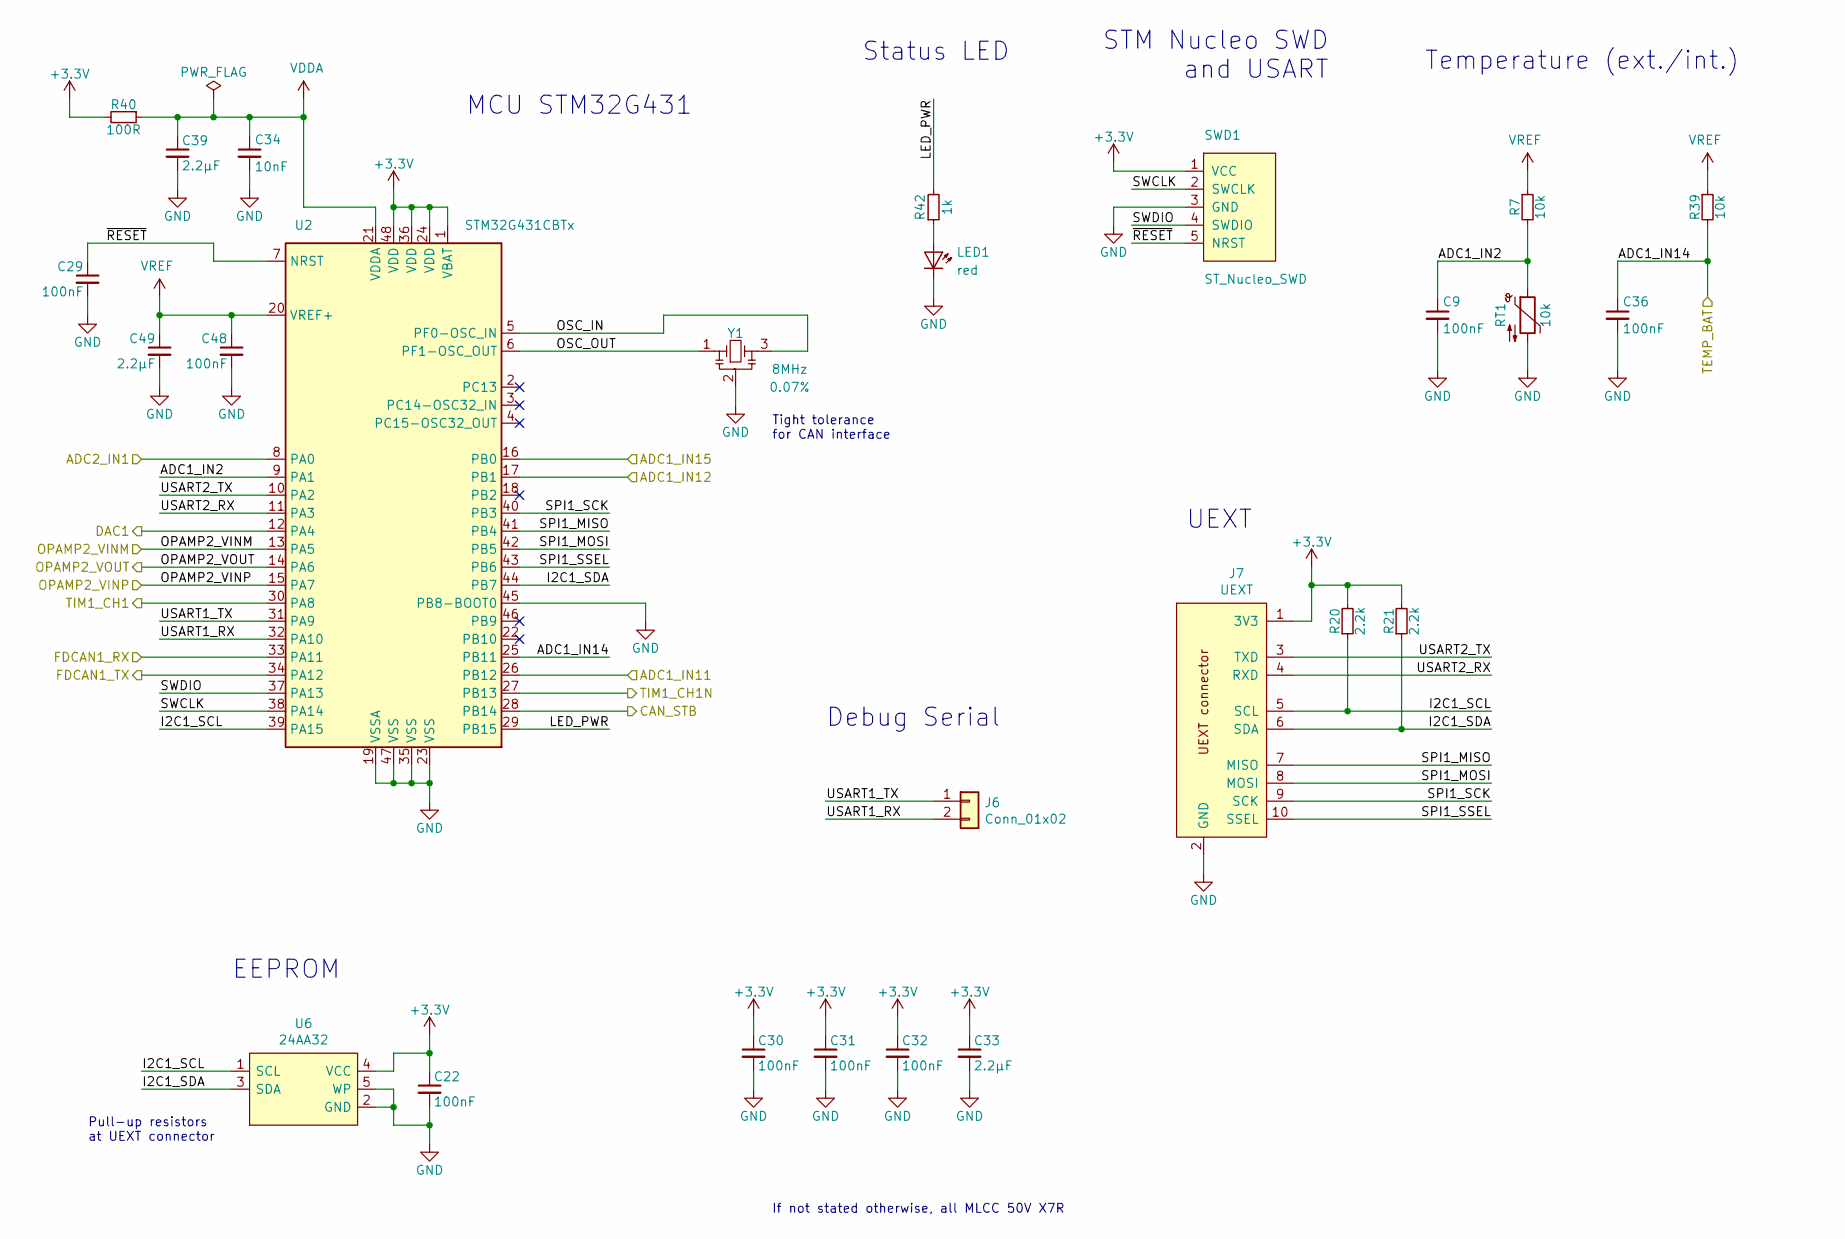
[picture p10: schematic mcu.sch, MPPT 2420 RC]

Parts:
C9, C22, C29, C30, C31, C32, C36, C48: 100nF; C_0603_1608; PartNumber GRM188R71H104KA93D
C33, C39, C49: 2.2µF; C_0603_1608; PartNumber GRM188R61E225KA12D
C34: 10nF; C_0603_1608; PartNumber GCM188R72A103KA37D
J6: Conn_01x02; PinHeader_1x02_P2.54mm_Vertical
J7: UEXT; Box_Header_2x05x2.54mm_Straight
LED1: red; LED_D3.0mm; PartNumber LTST-C190KRKT
R7, R39: 10k; R_0603_1608; PartNumber RC0603FR-0710KL
R20, R21: 2.2k; R_0603_1608; PartNumber RC0603FR-072K2L
R40: 100R; R_0603_1608; PartNumber RC0603FR-07100RL
R42: 1k; R_0603_1608; PartNumber RC0603FR-071KL
RT1: 10k; R_0603_1608; PartNumber NTCG163JF103FT1S
SWD1: ST_Nucleo_SWD; PinHeader_1x05_P2.54mm_Vertical; PartNumber Standard 2.54 mm pitch 1x5 pin header
U2: STM32G431CBTx; LQFP-48_7x7mm_P0.5mm; PartNumber STM32G431CBT6
U6: 24AA32; SOT-23-5; PartNumber 24AA32AFT-I/OT
Y1: 8MHz; Resonator_Murata_CSTNE; PartNumber CSTNE8M00GH5C000R0

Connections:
+3V3: C22.1, C30.1, C31.1, C32.1, C33.1, J7.1 (3V3), R20.2, R21.2, R40.2, SWD1.1 (VCC), U2.1 (VBAT), U2.24 (VDD), U2.36 (VDD), U2.48 (VDD), U6.4 (VCC); also elsewhere on the board
/CAN bus/CAN_RX: U2.33 (PA11); also elsewhere on the board
/CAN bus/CAN_STB: U2.28 (PB14); also elsewhere on the board
/CAN bus/CAN_TX: U2.34 (PA12); also elsewhere on the board
/DC/DC/PWM_HS: U2.30 (PA8); also elsewhere on the board
/DC/DC/PWM_LS: U2.27 (PB13); also elsewhere on the board
/MCU/ADC1_IN2: C9.1, R7.2, RT1.1, U2.9 (PA1)
/MCU/ADC1_IN11: U2.26 (PB12); also elsewhere on the board
/MCU/ADC1_IN12: U2.17 (PB1); also elsewhere on the board
/MCU/ADC1_IN15: U2.16 (PB0); also elsewhere on the board
/MCU/ADC2_IN1: U2.8 (PA0); also elsewhere on the board
/MCU/DAC1: U2.12 (PA4); also elsewhere on the board
/MCU/I2C1_SCL: J7.5 (SCL), R20.1, U2.39 (PA15), U6.1 (SCL)
/MCU/I2C1_SDA: J7.6 (SDA), R21.1, U2.44 (PB7), U6.3 (SDA)
/MCU/LED_PWR: R42.2, U2.29 (PB15)
/MCU/OPAMP2_VINM: U2.13 (PA5); also elsewhere on the board
/MCU/OPAMP2_VINP: U2.15 (PA7); also elsewhere on the board
/MCU/OPAMP2_VOUT: U2.14 (PA6); also elsewhere on the board
/MCU/OSC_IN: U2.5 (PF0-OSC_IN), Y1.3
/MCU/OSC_OUT: U2.6 (PF1-OSC_OUT), Y1.1
/MCU/SPI1_MISO: J7.7 (MISO), U2.41 (PB4)
/MCU/SPI1_MOSI: J7.8 (MOSI), U2.42 (PB5)
/MCU/SPI1_SCK: J7.9 (SCK), U2.40 (PB3)
/MCU/SPI1_SSEL: J7.10 (SSEL), U2.43 (PB6)
/MCU/SWCLK: SWD1.2 (SWCLK), U2.38 (PA14)
/MCU/SWDIO: SWD1.4 (SWDIO), U2.37 (PA13)
/MCU/TEMP_BAT: C36.1, R39.2, U2.25 (PB11); also elsewhere on the board
/MCU/USART1_RX: J6.2, U2.32 (PA10)
/MCU/USART1_TX: J6.1, U2.31 (PA9)
/MCU/USART2_RX: J7.4 (RXD), U2.11 (PA3)
/MCU/USART2_TX: J7.3 (TXD), U2.10 (PA2)
/MCU/~RESET: C29.1, SWD1.5 (NRST), U2.7 (NRST)
GND: C9.2, C22.2, C29.2, C30.2, C31.2, C32.2, C33.2, C34.2, C36.2, C39.2, C48.2, C49.2, J7.2 (GND), LED1.1 (K), RT1.2, SWD1.3 (GND), U2.19 (VSSA), U2.23 (VSS), U2.35 (VSS), U2.45 (PB8-BOOT0), U2.47 (VSS), U6.2 (GND), U6.5 (WP), Y1.2; also elsewhere on the board
unnamed: LED1.2 (A), R42.1
VDDA: C34.1, C39.1, R40.1, U2.21 (VDDA)
VREF: C48.1, C49.1, R7.1, R39.1, U2.20 (VREF+)

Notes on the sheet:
Status LED
MCU STM32G431
STM Nucleo SWD and USART
Tight tolerance for CAN interface
EEPROM
If not stated otherwise, all MLCC 50V X7R
Temperature (ext./int.)
UEXT
Pull-up resistors at UEXT connector
Debug Serial

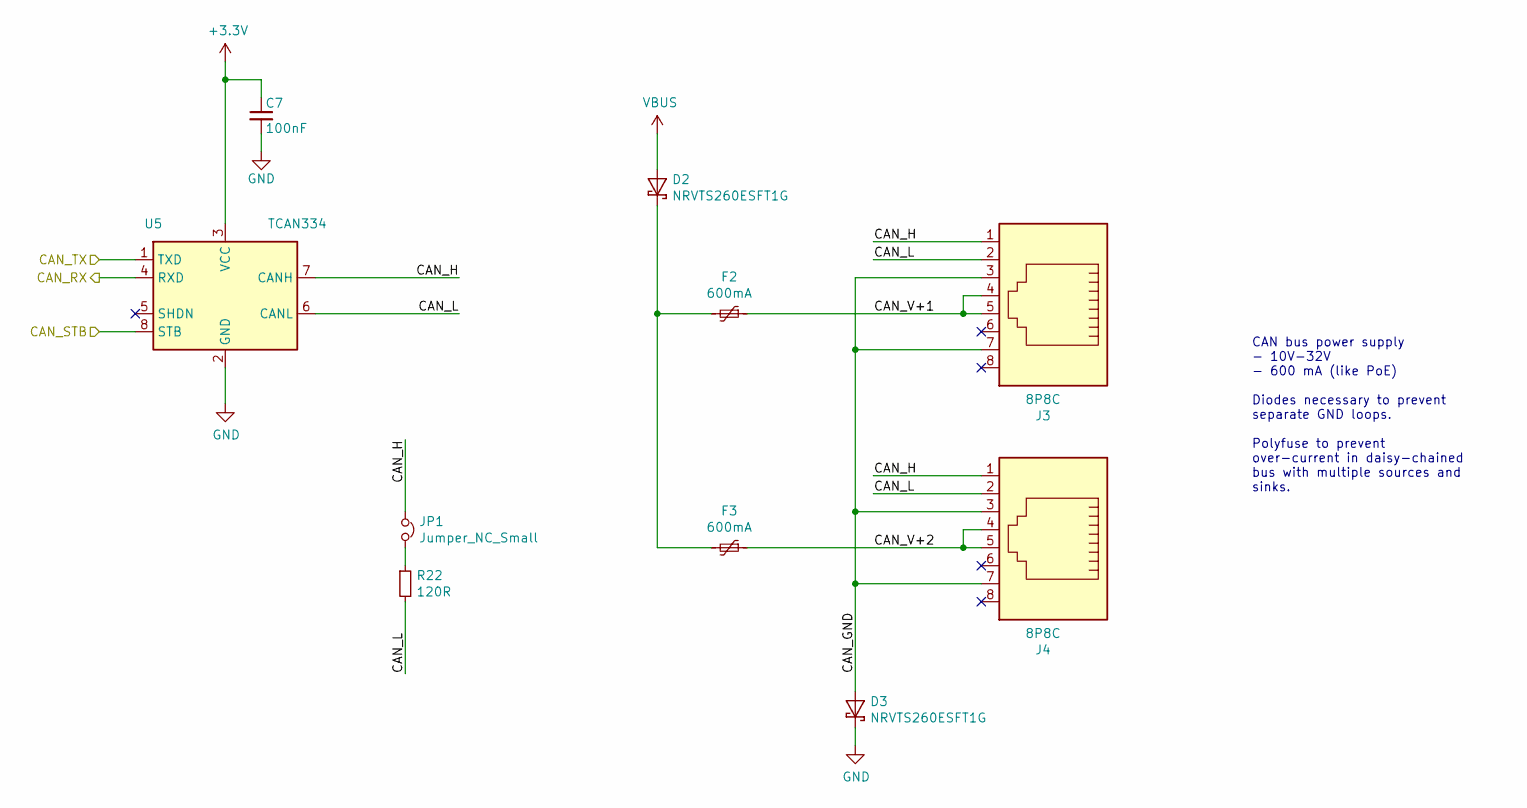
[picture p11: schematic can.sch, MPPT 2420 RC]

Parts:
C7: 100nF; C_0603_1608; PartNumber GRM188R71H104KA93D
D2, D3: NRVTS260ESFT1G; D_SOD-123; PartNumber NRVTS260ESFT1G
F2, F3: 600mA; Fuse_1206_3216Metric
J3, J4: 8P8C; RJ45_8P8C; PartNumber 54602-908LF
JP1: Jumper_NC_Small; PinHeader_1x02_P2.54mm_Vertical
R22: 120R; R_1206_3216
U5: TCAN334; SOIC-8_3.9x4.9mm_Pitch1.27mm; PartNumber TCAN334DR

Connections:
+3V3: C7.1, U5.3 (VCC); also elsewhere on the board
/CAN bus/CAN_GND: D3.2 (A), J3.3, J3.7, J4.3, J4.7
/CAN bus/CAN_H: J3.1, J4.1, JP1.1, U5.7 (CANH)
/CAN bus/CAN_L: J3.2, J4.2, R22.2, U5.6 (CANL)
/CAN bus/CAN_RX: U5.4 (RXD); also elsewhere on the board
/CAN bus/CAN_STB: U5.8 (STB); also elsewhere on the board
/CAN bus/CAN_TX: U5.1 (TXD); also elsewhere on the board
/CAN bus/CAN_V+1: F2.1, J3.4, J3.5
/CAN bus/CAN_V+2: F3.1, J4.4, J4.5
GND: C7.2, D3.1 (K), U5.2 (GND); also elsewhere on the board
unnamed: D2.1 (K), F2.2, F3.2
unnamed: JP1.2, R22.1
VBUS: D2.2 (A); also elsewhere on the board

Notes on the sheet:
CAN bus power supply - 10V-32V - 600 mA (like PoE) Diodes necessary to prevent separate GND loops. Polyfuse to prevent over-current in daisy-chained bus with multiple sources and sinks.

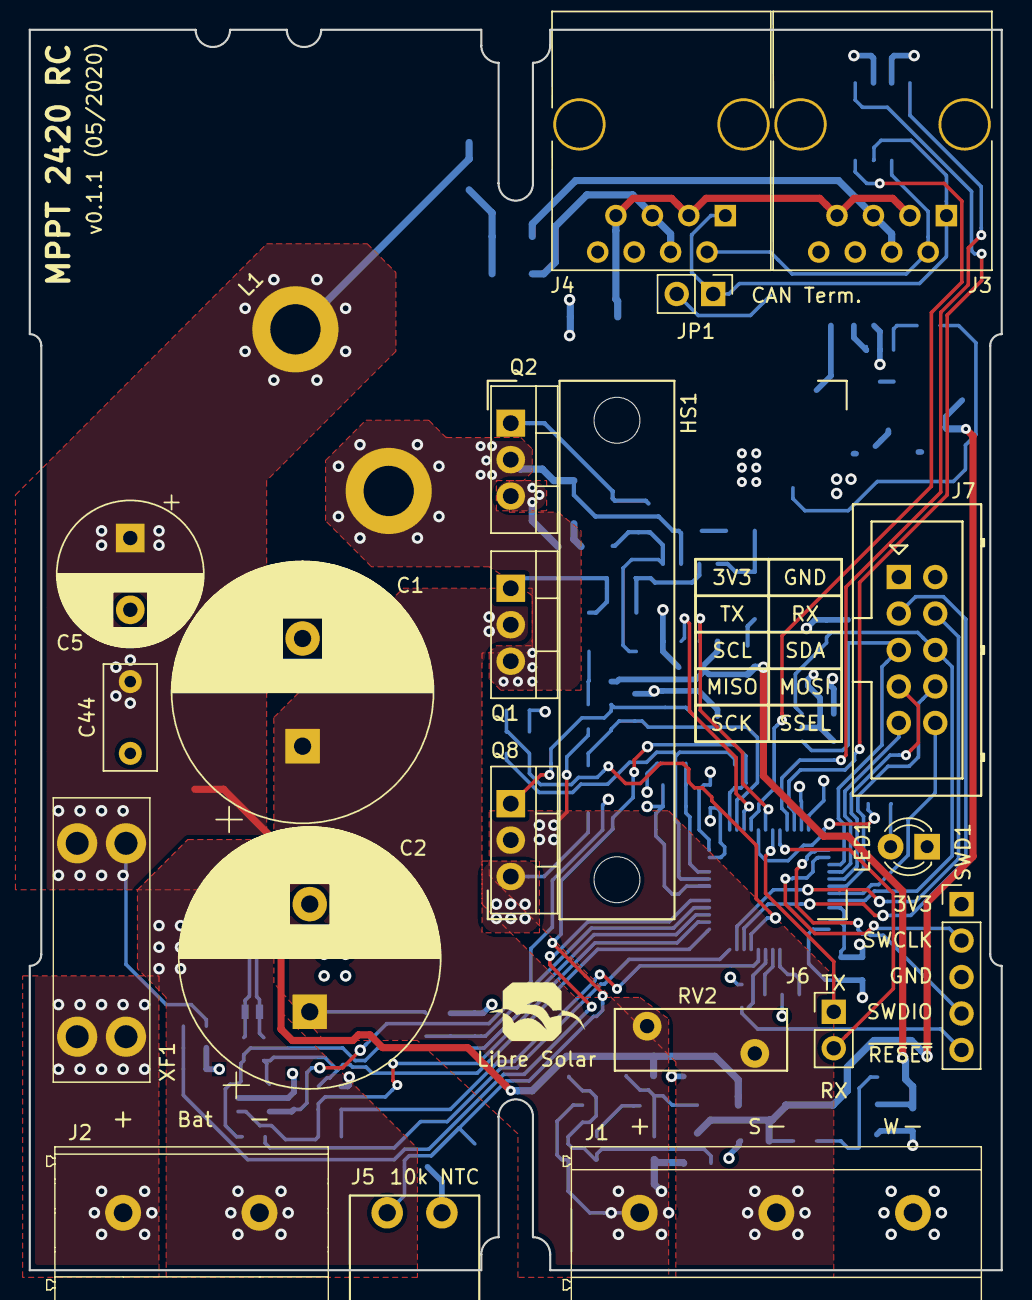
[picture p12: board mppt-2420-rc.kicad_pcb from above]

Board: 4 copper layers, 67.7 x 86.4 mm, 120 parts (0 on the bottom side), 71 nets.

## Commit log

2020-05-15 Initial version ordered (v0.1)
    [can.sch, dcdc.sch, mcu.sch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]
2020-05-31 Fix errors after first prototype build-up
    - Collision of capacitors with MOSFET clamps
    - BOOT0 pin tied to GND
    - Assignment of a few previously unasigned passives
    - Add optional debug serial connector
    [can.sch, dcdc.sch, mcu.sch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]
2020-06-14 Fix some references and part numbers
    See issues #3, #5, #7, #8 and #9.
    [can.sch, dcdc.sch, mcu.sch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]
2020-06-17 Clean up BOM and add build folder for generated files
    [can.sch, dcdc.sch, mcu.sch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]
